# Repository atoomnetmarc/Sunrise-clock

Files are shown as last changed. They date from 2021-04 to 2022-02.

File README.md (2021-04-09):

# Status

**Experimental. Do not replicate.**

# Sunrise clock-hardware

Schematic and PCB files of the Sunrise clock. This sunrise clock tries to gently wake the user from its sleep using digital leds (SK6812) to simulate a sunrise and simultaneously playing soothing sounds through its crappy speaker using a I2S mono amplifier.\
1 display was not enough to view the time when the user has trouble dealing with dry eye syndrome so there are 3 displays capable of displaying a few characters each with a large font. Also, no touch screen so the user is able to change settings without looking using large-ish tactile buttons.

How the sunrise clock could look like:

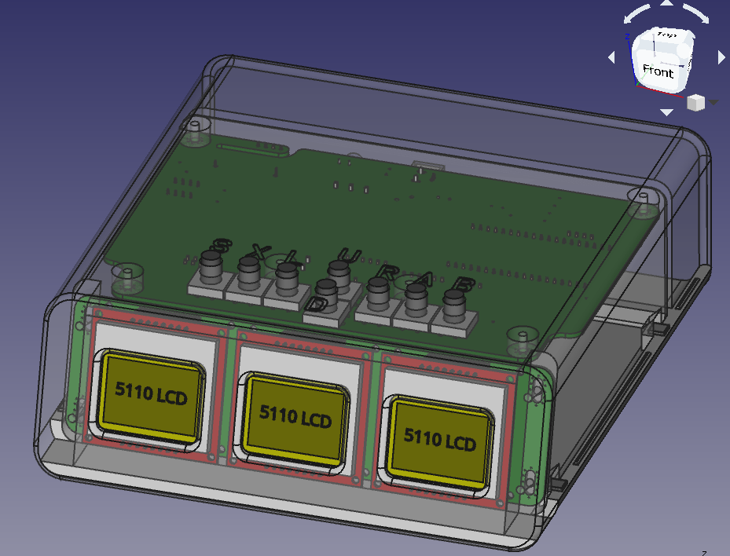
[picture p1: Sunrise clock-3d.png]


My [Kicad library](https://github.com/atoomnetmarc/ATOOMNETKICAD) is used in this project.



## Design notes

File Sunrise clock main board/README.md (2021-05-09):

# Status

**Experimental. Do not replicate.**

# Checklist V1.0 PCB

Worky (after workaround)?

:ballot_box_with_check: SD card auto disconnect when programming via USB\
:ballot_box_with_check: SD card, 1-bit SDIO\
:ballot_box_with_check: SD card, HSPI\
:ballot_box_with_check: RTC battery voltage follower opamp\
:ballot_box_with_check: 3.3V I2C\
:ballot_box_with_check: 5V I2C\
:ballot_box_with_check: INA219 current/power measuring\
:ballot_box_with_check: AT24C512C EEPROM\
:ballot_box_with_check: DS3231MZ mems RTC\
:ballot_box_with_check: BME280 sensor\
:ballot_box_with_check: MCP23017 I/O expander\
:ballot_box_with_check: LDR\
:ballot_box_with_check: LCD displays\
:ballot_box_with_check: Neopixel\
:ballot_box_with_check: Polyfuse F1\
:ballot_box_with_check: GPO2\
:ballot_box_with_check: I2S audio amplifier left channel (mono)\
:black_square_button: I2S audio amplifier right channel

# Errata

## V1.1

- Not build yet.

## V1.0

- VREF2 of U6 is incorrectly connected to +5V. It should be connected to EN. Workaround by disconnecting trace to VREF2 (pin7) and then connect EN (pin8) and VREF2 together.
- BME280 module A5 is a 5V one. Changed it for a 3.3V one. Workaround by disconnecting VCC from 5V and connect it to 3V.
- VIH of U8 74AHC125D on 5V too low for ESP32 output. Workaround by changing U8 from 74AHC125D to 74AHCT125D.
- INTA output voltage of MCP23017 exceeding input voltage of ESP32. Workaround by adding a 4K7/10K resistor divider.
- When powering the ESP32 by USB, the entire boards gets powered including the LED-strip which can potentially pull more than USB can provide. Workaround by moving D1 from parallel to ground and 5V to in series of 5V.
- External IO current measuring does not work with loads under 200mA and not great above that. Workaround by fitting a INA219 module between the 5V input of J1 and the rest of the board.



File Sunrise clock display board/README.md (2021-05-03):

# Status

**Experimental. Do not replicate.**

# Checklist V1.0 PCB

Worky (after bodge fix)?

:ballot_box_with_check: SD card auto disconnect when programming via USB
:ballot_box_with_check: SD card, 1-bit SDIO
:ballot_box_with_check: SD card, HSPI
:ballot_box_with_check: RTC battery voltage follower opamp
:ballot_box_with_check: LED-strip current measuring opamp
:black_square_button: 3.3V I2C
:black_square_button: 5V I2C
:black_square_button: AT24C512C EEPROM
:black_square_button: DS3231MZ mems RTC
:black_square_button: BME280 sensor
:black_square_button: MCP23017 I/O expander
:black_square_button: LDR
:black_square_button: LCD displays
:black_square_button: Neopixel
:black_square_button: Polyfuse F1
:black_square_button: GPO2
:black_square_button: I2S audio amplifier left channel (mono)
:black_square_button: I2S audio amplifier right channel

# Errata

## V1.1

- Not build yet.

## V1.0

- VREF2 of U6 is incorrectly connected to +5V. It should be connected to EN. Workaround by disconnecting trace to VREF2 (pin7) and then connect EN (pin8) and VREF2 together.
- BME280 module A5 is a 5V one. Changed it for a 3.3V one. Workaround by disconnecting VCC from 5V and connect it to 3V.
- VIH of U8 74AHC125D on 5V too low for ESP32 output. Workaround by changing U8 from 74AHC125D to 74AHCT125D.



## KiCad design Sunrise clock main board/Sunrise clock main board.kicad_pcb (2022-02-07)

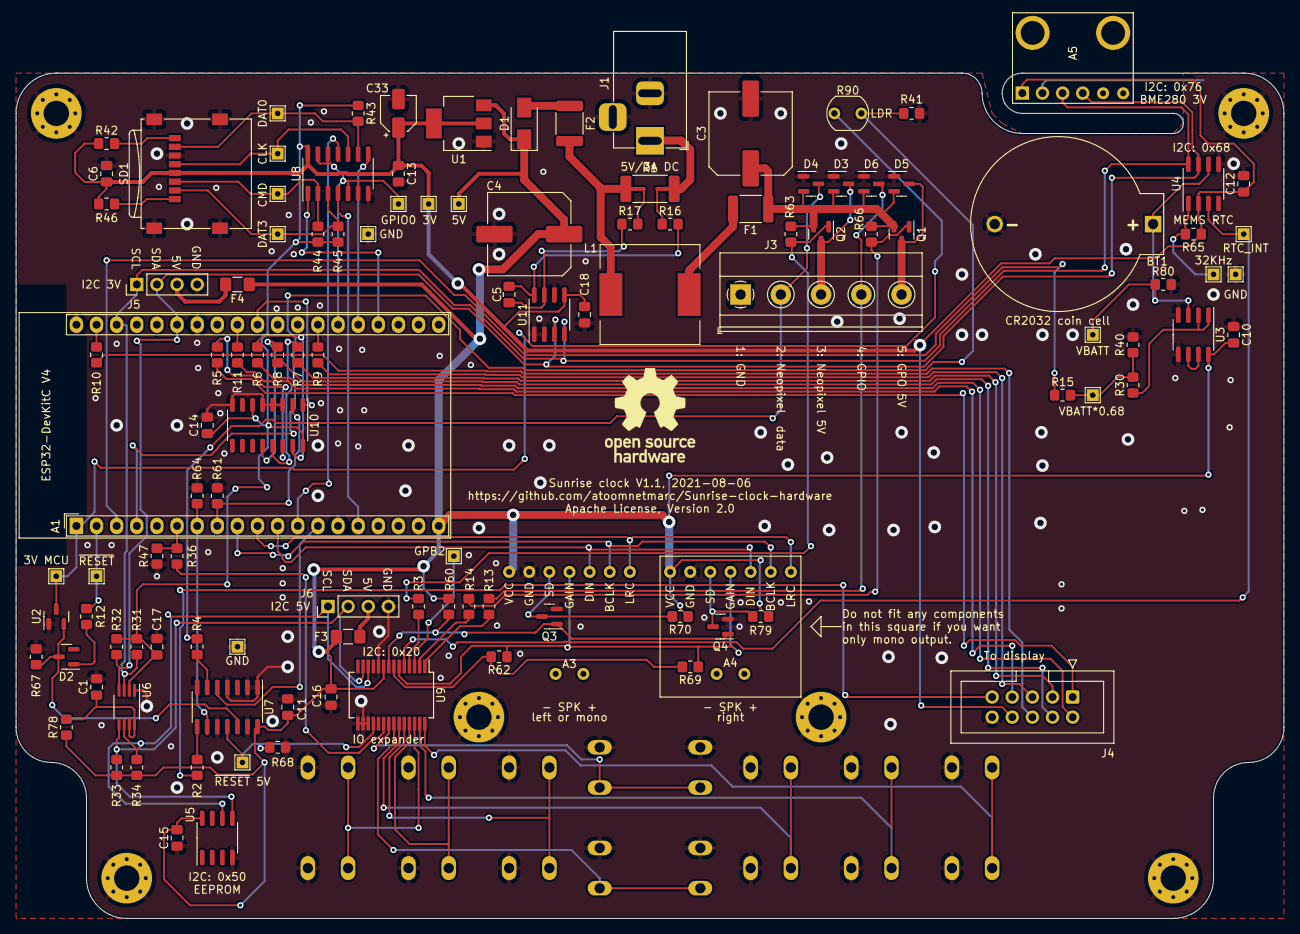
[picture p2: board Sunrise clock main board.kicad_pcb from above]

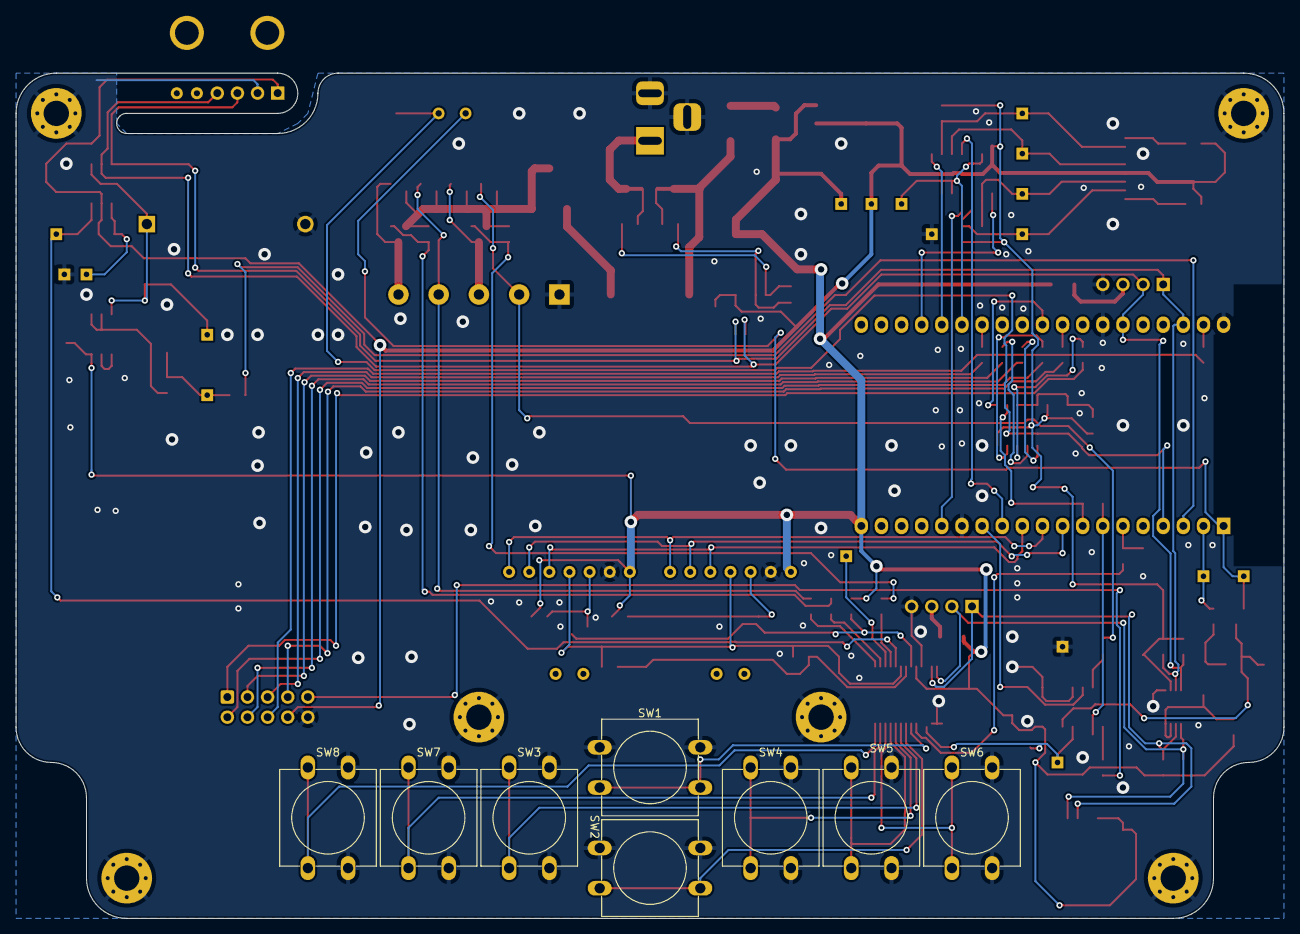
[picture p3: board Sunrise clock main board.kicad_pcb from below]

Board: 2 copper layers, 160.0 x 106.7 mm, 133 parts (8 on the bottom side), 92 nets.

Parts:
A1: ESP32-DevKitC
A3, A4: max98357
A5: BME280 module 3V; bme280_3V
BT1: CR2032; BatteryHolder-cr2032
C1: 100pF 16V X7R; C_0805_2012Metric_Pad1.18x1.45mm_HandSolder
C3, C4: 470uF/16V; C_Elec_10x10.2
C5: 1uF; C_0805_2012Metric_Pad1.18x1.45mm_HandSolder
C6: 10uF; C_0805_2012Metric_Pad1.18x1.45mm_HandSolder
C10, C11, C12, C13, C14, C15, C16, C17, C18: 100nF; C_0805_2012Metric_Pad1.18x1.45mm_HandSolder
C33: 33uF/6.3V; CP_Elec_4x5.4
D1: SS34; D_SMA
D2, D3, D4, D5, D6: BAV99; SOT-23
F1, F2: Polyfuse 1.5A >=6V; Fuse_1812_4532Metric_Pad1.30x3.40mm_HandSolder
F3, F4: Polyfuse 250mA >=6V; Fuse_1206_3216Metric_Pad1.42x1.75mm_HandSolder
H1, H2, H3, H4, H5, H6: MountingHole_Pad; MountingHole_3.2mm_M3_Pad_Via
J1: Barrel_Jack_Switch; BarrelJack_Horizontal
J3: Screw terminal/dnf; TerminalBlock_Phoenix_MKDS-1,5-5-5.08_1x05_P5.08mm_Horizont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
J4: Conn_02x05_Odd_Even; IDC-Header_2x05_P2.54mm_Vertical
J5, J6: Conn_01x04_Male; PinHeader_1x04_P2.54mm_Vertical
L1: 22uH 3A; L_12x12mm_H8mm
LOGO1: Logo_Open_Hardware_Large; OSHW-Logo_11.4x12mm_SilkScreen
NT1, NT2: Net-Tie_2; NetTie-2_SMD_Pad0.5mm
Q1, Q2: IRML2244; SOT-23
Q3, Q4: 2N7002; SOT-23
R1: 0R05; R_2512_6332Metric_Pad1.40x3.35mm_HandSolder
R2, R3, R4, R5, R6, R7, R8, R9, R10, R11, R12, R13, R14, R15: 100R; R_0805_2012Metric_Pad1.20x1.40mm_HandSolder
R16, R17: 10R; R_0805_2012Metric_Pad1.20x1.40mm_HandSolder
R30, R31, R32, R33, R34, R36: 4k7; R_0805_2012Metric_Pad1.20x1.40mm_HandSolder
R40, R41, R42, R43, R44, R45, R46, R47: 10k; R_0805_2012Metric_Pad1.20x1.40mm_HandSolder
R60, R61, R62, R63, R64, R65, R66, R67, R68, R69, R70: 100k; R_0805_2012Metric_Pad1.20x1.40mm_HandSolder
R78: 200k; R_0805_2012Metric_Pad1.20x1.40mm_HandSolder
R79: 560k; R_0805_2012Metric_Pad1.20x1.40mm_HandSolder
R80: 10M; R_0805_2012Metric_Pad1.20x1.40mm_HandSolder
R90: LDR GL5528; R_LDR_5.1x4.3mm_P3.4mm_Vertical
SD1: Micro_SD_Card; microSD_HC_Wuerth_693072010801
SW1, SW2, SW3, SW4, SW5, SW6, SW7, SW8: SW_Push; SW_PUSH-12mm
TP1, TP3, TP4, TP6, TP7, TP8, TP9, TP10, TP11, TP12, TP13, TP14, TP15, TP16, TP17, TP18, TP19, TP20: TestPoint; TestPoint_THTPad_1.5x1.5mm_Drill0.7mm
U1: NCP1117LPST33T3G; SOT-223-3_TabPin2
U2: MAX809S; SOT-23
U3: LM358DR; SOIC-8_3.9x4.9mm_P1.27mm
U4: DS3231MZ; SOIC-8_3.9x4.9mm_P1.27mm
U5: AT24C512C-SSHD; SOIC-8_3.9x4.9mm_P1.27mm
U6: PCA9306DCTR; MSOP-8_3x3mm_P0.65mm
U7: 74AHCT125D; SO-14_3.9x8.65mm_P1.27mm
U8: 74HC4066D; SO-14_3.9x8.65mm_P1.27mm
U9: MCP23017_SP; SSOP-28_5.3x10.2mm_P0.65mm
U10: 74HC138D; SO-16_3.9x9.9mm_P1.27mm
U11: INA219AxD; SOIC-8_3.9x4.9mm_P1.27mm

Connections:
3V_MCU: A1.1 (3V3_OUT), R90.1, TP6.1, U2.3 (VDD)
+3V3: A5.1 (VIN), C6.1, C12.1, C13.1, C14.1, C17.1, C18.1, C33.1, J4.8, R31.1, R32.1, R42.1, R43.1, R44.1, R45.1, R46.1, R65.1, SD1.4 (VDD), TP4.1, U1.2 (VO), U4.2 (VCC), U6.2 (VREF1), U8.14 (VDD), U10.6 (E3), U10.16 (VCC), U11.5 (VS)
+5V: A1.19 (5V_IN), A3.7 (VCC), A4.7 (VCC), C4.1, C10.1, C11.1, C15.1, C16.1, D1.1 (K), F3.2, F4.1, R33.1, R34.1, R60.2, R70.2, R78.1, R79.2, TP3.1, U1.3 (VI), U3.8 (V+), U5.8 (VCC), U7.14 (VCC), U9.9 (VDD)
+5VL: F2.2, L1.1, NT1.1, R1.1
+BATT: BT1.1 (+), R80.1, TP9.1, U3.3 (+), U4.6 (VBAT)
/Input/32KHz: R65.2, TP10.1, U4.1 (32KHZ)
/Output/GPO2_5V: D5.3 (K), J3.5, Q1.3 (D)
/Output/NEOPIXEL_5V: D3.3 (K), J3.3, Q2.3 (D)
/Output/NEOPIXEL_DOUT: D4.3 (K), J3.2, R4.1
/Power/VBATT*0.68: R15.2, R30.2, R40.1, TP8.1
/Storage/CLK: SD1.5 (CLK), TP15.1, U8.10
/Storage/CMD: R44.2, SD1.3 (CMD), TP14.1, U8.2
/Storage/DAT0: R43.2, SD1.7 (DAT0), TP16.1, U8.9
/Storage/DAT1: R42.2, SD1.8 (DAT1)
/Storage/DAT2: R46.2, SD1.1 (DAT2)
/Storage/DAT3: R45.2, SD1.2 (DAT3/CD), TP13.1, U8.3
EXP_INT: R36.1, U9.20 (INTA)
GND: A1.14 (GND), A1.32 (GND), A1.38 (GND), A3.6 (GND), A4.6 (GND), A5.2 (GND), BT1.2 (-), C1.2, C3.2, C4.2, C6.2, C10.2, C11.2, C12.2, C13.2, C14.2, C15.2, C16.2, C17.2, C18.2, C33.2, D3.1 (K), D4.1 (K), D5.1 (K), D6.1 (K), H1.1, H2.1, H3.1, H4.1, H5.1, H6.1, J1.2, J1.3, J3.1, J4.10, J5.4, J6.4, Q3.2 (S), Q4.2 (S), R40.2, R41.2, R47.1, R61.1, R64.2, R67.2, R68.2, R80.2, SD1.6 (VSS), SD1.9 (SHIELD), SW1.2, SW2.2, SW3.2, SW4.2, SW5.2, SW6.2, SW7.2, SW8.2, TP1.1, TP19.1, TP20.1, U1.1 (GND), U2.1 (GND), U3.4 (V-), U3.5 (+), U4.5 (GND), U5.4 (GND), U6.1 (GND), U7.1, U7.2, U7.4, U7.7 (GND), U7.10, U7.13, U8.7 (VSS), U9.10 (VSS), U9.15 (A0), U9.16 (A1), U9.17 (A2), U10.3 (A2), U10.4 (E1), U10.5 (E2), U10.8 (GND), U11.1 (A1), U11.2 (A0), U11.6 (GND)
GPA0: SW1.1, U9.21 (GPA0)
GPA1: SW2.1, U9.22 (GPA1)
GPA2: SW3.1, U9.23 (GPA2)
GPA3: SW4.1, U9.24 (GPA3)
GPA4: SW5.1, U9.25 (GPA4)
GPA5: SW6.1, U9.26 (GPA5)
GPA6: SW7.1, U9.27 (GPA6)
GPA7: SW8.1, U9.28 (GPA7)
GPIO0: A1.25 (BH/IO0), TP12.1, U8.5, U8.6, U8.12, U8.13
GPIO1: R13.2, U9.1 (GPB0)
GPIO5: A1.29 (SPI_CS0/BH/IO5), U10.1 (A0)
GPIO33: A1.8 (XTAL32K/IO33), R61.2, U10.2 (A1)
GPO2: R14.2, U9.2 (GPB1)
I2S_BCK: A1.9 (IO25/DAC1), A3.2 (BLCK), A4.2 (BLCK)
I2S_DATA: A1.11 (IO27), A3.3 (DIN), A4.3 (DIN)
I2S_GAIN0: A3.4 (GAIN), A4.4 (GAIN), R62.1, R69.1, U9.6 (GPB5)
I2S_GAIN1: R62.2, R69.2, U9.7 (GPB6)
I2S_SD: Q3.1 (G), Q4.1 (G), R60.1, U9.8 (GPB7)
I2S_WS: A1.10 (IO26/DAC2), A3.1 (LRC), A4.1 (LRC)
LCD1_~CE: J4.2, R6.1
LCD2_~CE: J4.3, R7.1
LCD3_~CE: J4.4, R8.1
LCD_CLK: J4.7, R11.1
LCD_DATA-~CMD: J4.5, R9.1
LCD_DIN: J4.6, R10.1
LCD_LED: A1.7 (XTAL32K/IO32), R64.1, U7.9
LCD_~RST: J4.1, R5.1
LDR: A1.4 (SENSOR_VN), R41.1, R90.2
NEOPIXEL_DATA: A1.13 (IO12/TDI/Bnc), U7.5
NEOPIXEL_~EN: R3.2, U9.4 (GPB3)
unnamed: A1.6 (IO35), R36.2, R47.2
unnamed: A1.26 (BL/IO4), R9.2
unnamed: A1.30 (SPI_CLK/IO18), R11.2
unnamed: A1.37 (SPI_MOSI/IO23), R10.2
unnamed: C1.1, R78.2, U6.7 (VREF2), U6.8 (EN)
unnamed: C3.1, D3.2 (A), D4.2 (A), D5.2 (A), D6.2 (A), F1.1, Q1.2 (S), Q2.2 (S), R63.1, R66.1
unnamed: C5.1, R16.1, U11.8 (IN+)
unnamed: C5.2, R17.1, U11.7 (IN-)
unnamed: D1.2 (A), F2.1
unnamed: D2.1 (K), R12.2
unnamed: D2.3 (K), R67.1, U2.2 (~RESET), U7.12
unnamed: D6.3 (K), J3.4, R13.1
unnamed: F1.2, L1.2
unnamed: F3.1, J6.3
unnamed: F4.2, J5.3
unnamed: J1.1, NT2.1, R1.2
unnamed: J4.9, R2.1
unnamed: Q1.1 (G), R14.1, R66.2
unnamed: Q2.1 (G), R3.1, R63.2
unnamed: R2.2, U7.8
unnamed: R4.2, U7.6
unnamed: R5.2, U10.14 (O1)
unnamed: R6.2, U10.15 (O0)
unnamed: R7.2, U10.13 (O2)
unnamed: R8.2, U10.12 (O3)
unnamed: R30.1, U3.1, U3.2 (-)
unnamed: TP18.1, U9.3 (GPB2)
unnamed: U3.6 (-), U3.7
RTC_INT: TP11.1, U4.3 (~INT/SQW), U9.5 (GPB4)
SCL_3V: A1.36 (IO22/SCL), A5.3 (SCL), J5.1, R31.2, U4.8 (SCL), U6.3 (SCL1), U11.4 (SCL)
SCL_5V: J6.1, R34.2, U5.6 (SCL), U6.6 (SCL2), U9.12 (SCK)
SDA_3V: A1.33 (IO21/SDA), A5.4 (SDA), J5.2, R32.2, U4.7 (SDA), U6.4 (SDA1), U11.3 (SDA)
SDA_5V: J6.2, R33.2, U5.5 (SDA), U6.5 (SDA2), U9.13 (SDA)
SD_CLK_SCK: A1.12 (IO14/TMS), U8.11
SD_CMD_MOSI: A1.23 (IO15/TDO/BH), U8.1
SD_D0_MISO: A1.24 (BL/IO2), U8.8
SD_SPI_SS: A1.15 (IO13/TCK), U8.4
VBAT_DIV: A1.3 (SENSOR_VP), R15.1
VIN+: NT2.2, R16.2
VIN-: NT1.2, R17.2
~RESET_5V: R68.1, TP17.1, U7.11, U9.18 (~RESET)
~RESET: A1.2 (EN), R12.1, TP7.1
~SDL: A3.5 (SD), Q3.3 (D), R70.1
~SDR: A4.5 (SD), Q4.3 (D), R79.1

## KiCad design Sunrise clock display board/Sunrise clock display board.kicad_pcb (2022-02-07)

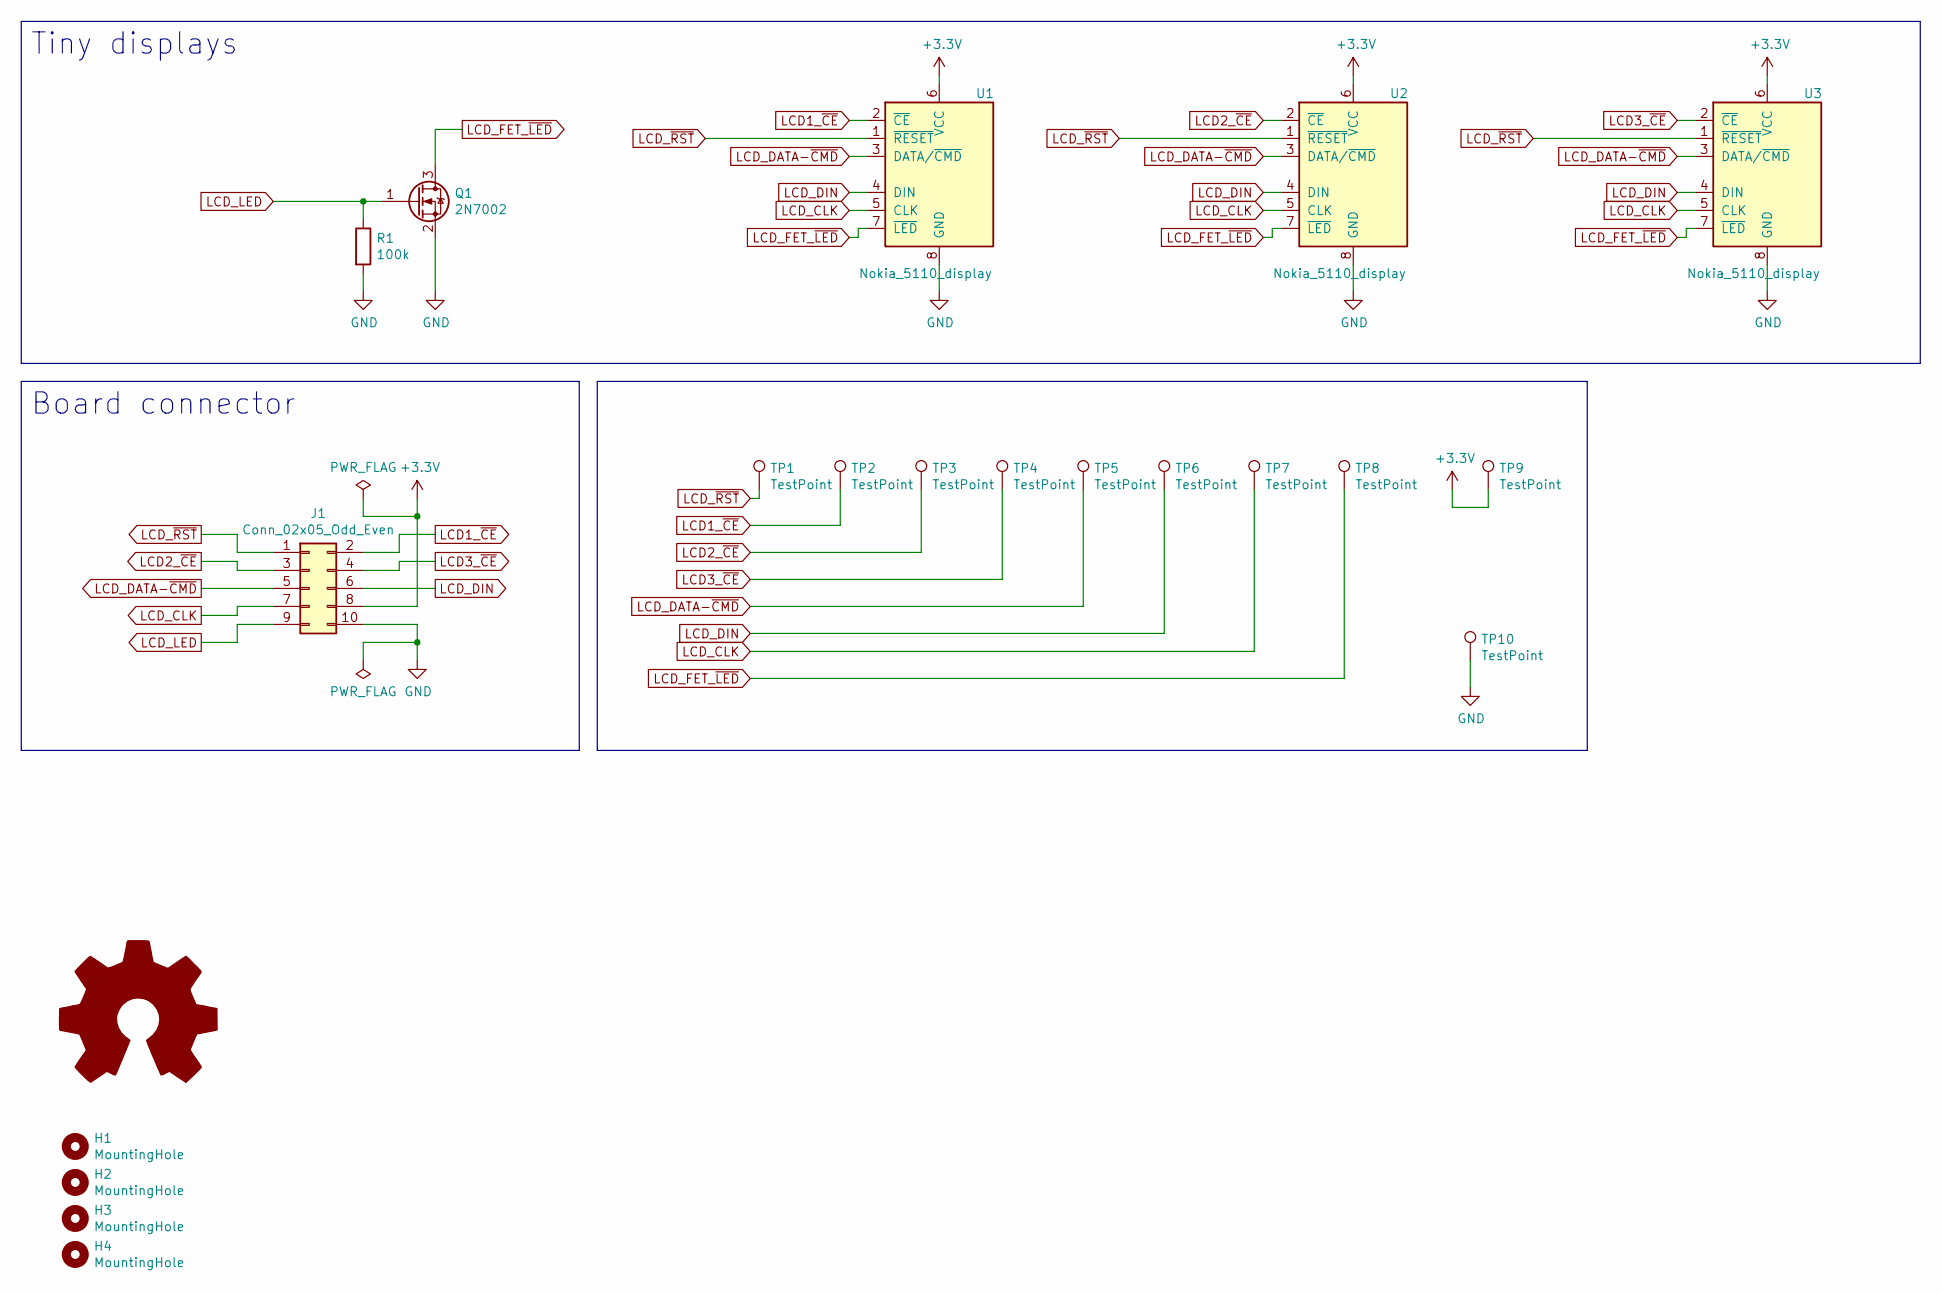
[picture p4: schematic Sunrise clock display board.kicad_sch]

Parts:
H1, H2, H3, H4: MountingHole; MountingHole_3.2mm_M3_Oval_5mm
J1: Conn_02x05_Odd_Even; IDC-Header_2x05_P2.54mm_Vertical
LOGO1: Logo_Open_Hardware_Large; OSHW-Logo_19x20mm_SilkScreen
Q1: 2N7002; SOT-23
R1: 100k; R_0805_2012Metric_Pad1.20x1.40mm_HandSolder
TP1, TP2, TP3, TP4, TP5, TP6, TP7, TP8, TP9, TP10: TestPoint; TestPoint_THTPad_1.5x1.5mm_Drill0.7mm
U1, U2, U3: Nokia_5110_display; Nokia_5110_display_module

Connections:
+3V3: J1.8, TP9.1, U1.6 (VCC), U2.6 (VCC), U3.6 (VCC)
GND: J1.10, Q1.2 (S), R1.2, TP10.1, U1.8 (GND), U2.8 (GND), U3.8 (GND)
LCD1_~CE: J1.2, TP2.1, U1.2 (~CE)
LCD2_~CE: J1.3, TP3.1, U2.2 (~CE)
LCD3_~CE: J1.4, TP4.1, U3.2 (~CE)
LCD_CLK: J1.7, TP7.1, U1.5 (CLK), U2.5 (CLK), U3.5 (CLK)
LCD_DATA-~CMD: J1.5, TP5.1, U1.3 (DATA/~CMD), U2.3 (DATA/~CMD), U3.3 (DATA/~CMD)
LCD_DIN: J1.6, TP6.1, U1.4 (DIN), U2.4 (DIN), U3.4 (DIN)
LCD_FET_~LED: Q1.3 (D), TP8.1, U1.7 (~LED), U2.7 (~LED), U3.7 (~LED)
LCD_LED: J1.9, Q1.1 (G), R1.1
LCD_~RST: J1.1, TP1.1, U1.1 (~RESET), U2.1 (~RESET), U3.1 (~RESET)

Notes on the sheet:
Board connector
Tiny displays

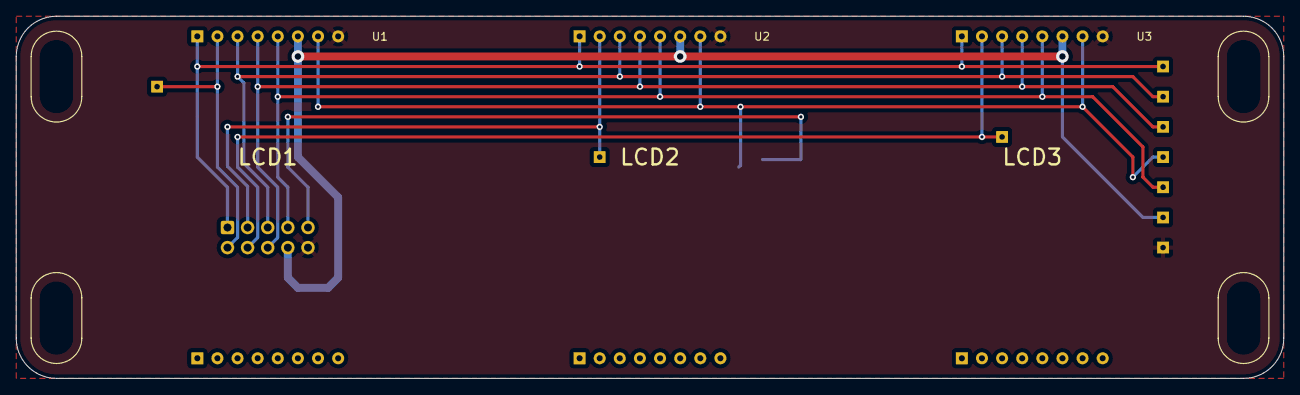
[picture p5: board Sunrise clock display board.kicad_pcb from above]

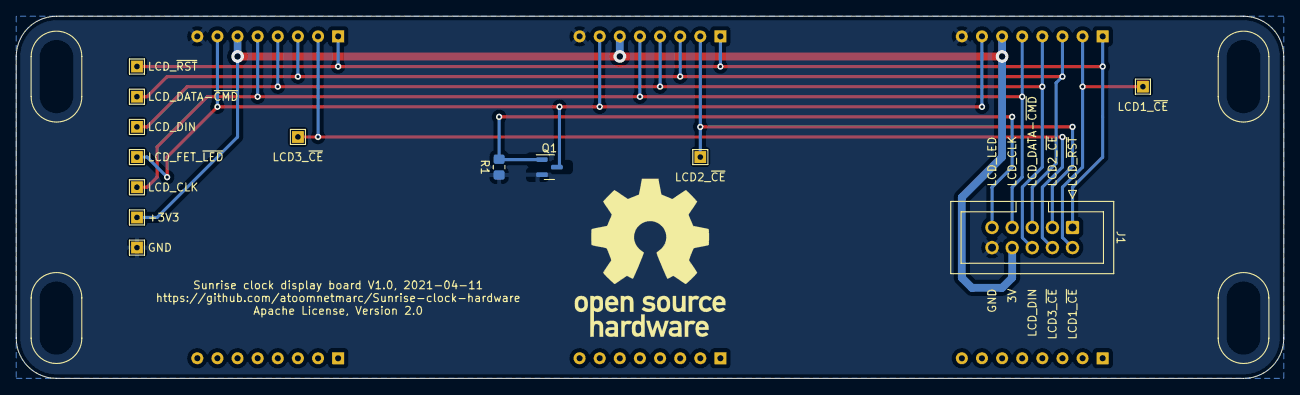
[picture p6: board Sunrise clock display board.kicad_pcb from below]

Board: 2 copper layers, 160.0 x 45.7 mm, 21 parts (14 on the bottom side), 11 nets.

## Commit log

2021-04-09 Initial commit.
    [Control.sch, Input.sch, Output.sch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]
2021-04-10 Now in stereo if you want.
    [Control.sch, Input.sch, Output.sch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]
2021-04-11 Added gerbers and bom.
    [Control.sch, Input.sch, Output.sch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]
2021-04-24 updated lcd footprint
    [Sunrise clock display board.kicad_pcb]
2021-05-02 Start of V1.1
    [Control.sch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]
2021-05-03 changed BME280 module to a 3v one
    [Input.sch, Sunrise clock main board.kicad_pcb]
2021-05-03 Started with checklist.
    [Input.sch, Output.sch, Power.sch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]
2021-05-03 More testing.
    [Control.sch, Sunrise clock main board.kicad_pcb]
2021-08-06 Changed INA219AxDCN to INA219AxD
    [Control.sch, Input.sch, Output.sch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]
2022-02-07 Update to Kicad 6.
    [Sunrise clock display board-B_Cu.gbl, Sunrise clock display board-B_Mask.gbs, Sunrise clock display board-B_Paste.gbp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]

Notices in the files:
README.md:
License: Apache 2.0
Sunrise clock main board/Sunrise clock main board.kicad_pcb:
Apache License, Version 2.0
